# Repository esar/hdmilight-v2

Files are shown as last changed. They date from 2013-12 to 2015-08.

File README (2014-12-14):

For latest version, go to http://hacks.esar.org.uk/

How to use:

1) Manufacture the HDMI receiver board that can be found in 
   the 'board' directory (CADSoft Eagle format).
2) Open the 'fpga/hdmilight.xise' project in Xilinx ISE and
   generate a bit file.
3) Edit the files under the config directory to configure
   the LEDs.
4) Edit 'Makefile' in the top level directory and set
   the DATA2MEM path for the Xilinx data2mem tool location
   on your system.
5) Run 'make' in the top level directory, which will build
   'tools/makemem', then the firmware image, then the config
   files, before merging the firmware and config into the
   final bitfile.
   The final result should be hdmilight.bit in the top
   level directory.
6) Upload hdmilight.bit to a Papilio Pro FPGA board
7) Install the HDMI receiver board on to the Papilio board.
8) Connect LED strips to output pins
9) Open a serial terminal to the Papilio
10) Connect HDMI source to receiver board
11) It should now be working.

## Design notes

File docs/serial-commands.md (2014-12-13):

Serial Console Commands
=======================

Get Area
--------

    GA index

* index (0-255): The index or range of indices of the area definition(s) that should be retrieved 

Set Area
--------

    SA index xmin xmax ymin ymax divshift

* index (0-255): The index or range of indices of the area definition(s) that should be set
* xmin (0-63): The left most column of the area's rectangle
* xmax (0-63): The right most column of the area's rectangle
* ymin (0-63): The upper row of the area's rectangle
* ymax (0-63): The lower row of the area's rectangle
* divshift (0-): The number of places to right-shift the accumulated R, G and B value for the area, or in other words the divisor used to calculate the average
 * 1 = divide by 2
 * 2 = divide by 4
 * 3 = divide by 8
 * etc.

Reset Area
----------

    RA

Get Colour Correction Matrix
----------------------------

    GC matrix row 

* matrix (0-15): The index or range of indices of the matrix(s) whose row(s) should be retrieved
* row (0-3): The index or range of indices of the row(s) that should be retrieved:
  * Row 0: defines how red input influences the output R, G and B
  * Row 1: defines how green input influences the output R, G and B
  * Row 2: defines how blue input influences the output R, G and B
  * Row 3: defines the constant value that should be applied to the output R, G and B

Set Colour Correction Matrix
----------------------------

    SC matrix row r g b

* matrix (0-15): The index or range of indices of the matrix(s) whose row(s) should be set
* row (0-3): The index or range of indices of the row(s) that should be set
* r (-255.999-255.999): The coefficient for R
* g (-255.999-255.999): The coefficient for G
* b (-255.999-255.999): The coefficient for B

Reset Colour Correction Matrix
------------------------------

    RC

The reset colour command resets all colour correction matrices to the identity matrix.

Get Delay
---------

    GD

Set Delay
---------

    SD frames usec smooth_ratio

* frames (0-7): The number of whole frames that the output should be delayed by
* usec (0-65535): The number of micro-seconds that the output should be delayed by
* smooth_ratio (0.000-1.000): A number that specifies how much of the new output colour comes from the previous output colour and how much comes from the current frame:
 * 0.000 = 100% from current frame
 * 1.000 = 100% from previous output

Reset Delay
-----------

    RD

The reset delay command disables all delay and temporal smoothing

Disable Format Switching
------------------------

    DF

The disable format switching command stops configurations from being loaded
from flash whenever the format of the incoming video changes.

Enable Format Switching
-----------------------

    EF

The enable format switching command enables loading of the configurations
specified in the format table when the input video format changes.

Get Gamma
---------

    GG table channel index

* table (0-7): The index or range of indices of the gamma correction table(s) whose values should be retrieved
* channel (0-2): The index or range of indices of the colour channel(s) whose values should be retrieved: 
 * 0 = red
 * 1 = green
 * 2 = blue
* index: The index or range of indices of the row(s) that should be retrieved (0-255)

Set Gamma
---------

    SG table channel index value

* table (0-7): The index or range of indices of the gamma correction table(s) whose values should be set
* channel (0-2): The index or range of indices of the colour channel(s) whose values should be set
* index (0-255): The index or range of indices of the row(s) that should be set

Reset Gamma
-----------

    RG

The reset gamma command resets all gamma tables to a linear ramp (gamma 1.0)

Get I2C
-------

    GI addr subaddr

* addr (0-255): The address of the component within the ADV7611 that should be queried:
 * IO: 0x98
 * CP: 0x44
 * HDMI: 0x68
 * Repeater: 0x64
 * EDID: 0x6C
 * InfoFrame: 0x7C
 * CEC: 0x80
 * DPLL: 0x4C
* subaddr (0-255): The address within the component that should be queried

Set I2C
-------

    SI addr subaddr value

* addr (0-255): The address of the component within the ADV7611 that should be queried:
 * IO: 0x98
 * CP: 0x44
 * HDMI: 0x68
 * Repeater: 0x64
 * EDID: 0x6C
 * InfoFrame: 0x7C
 * CEC: 0x80
 * DPLL: 0x4C
* subaddr (0-255): The address within the component that should be queried
* value (0-255): The value that should be written to the register

Reset I2C
---------

    RI

The reset I2C command sets the registers as described in the table
in config_hdmi.h

Get Memory
----------

    GM index

* index (0-63): The index of the configuration that should be retrieved from flash

Get Output Map
--------------

    GO output light

* output (0-7): The index or indices of the output channels whose mapping should be retrieved
* light (0-511): The index or indices of the LED(s) whose mapping should be retrieved

Set Output Map
--------------

    SO output light area colour gamma enable

* output (0-7): The index or indices of the output channels whose mapping should be set
* light (0-511): The index or indices of the LED(s) whose mapping should be set
* area (0-255): The index of the area definition that the LED(s) should use
* colour (0-15): The index of the colour matrix that the LED(s) shoudl use
* gamma (0-7): The index of the gamma table that the LED(s) should use
* enable (0-1): 
 * 1 = enabled
 * 0 = disabled

Reset Output
------------

    RO

The reset output command sets the first 256 LEDs for all outputs to use the 256 area definitions in order, so LED 0 uses area 0, LED 1 uses area 1, and so on. All LEDs are set to use colour matrix 0 and gamma table 0. The remaining 256 LEDs on each output are disabled.

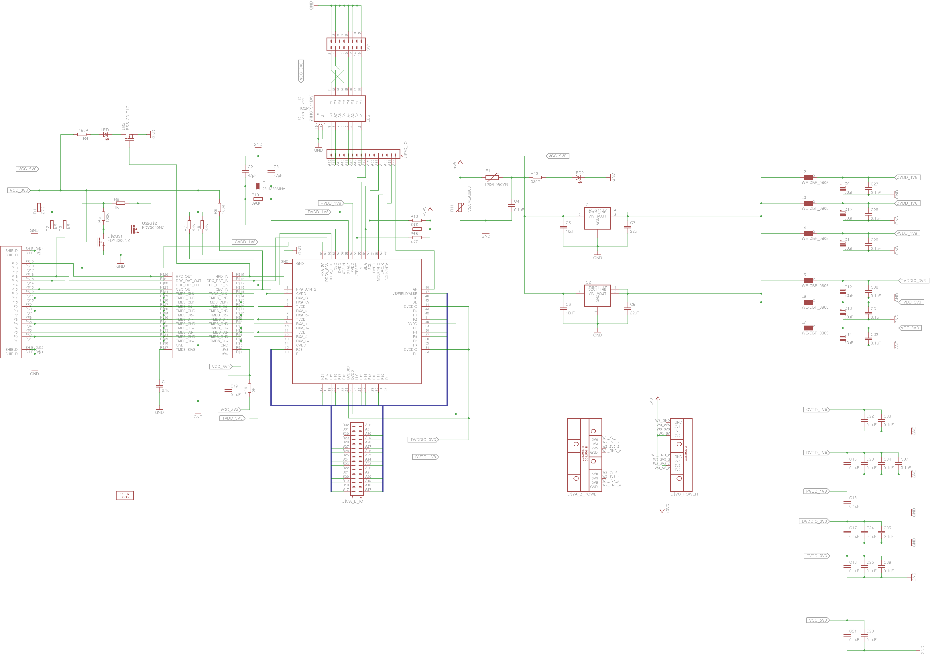
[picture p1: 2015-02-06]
board/hdmilight-schematic-v1.1.png

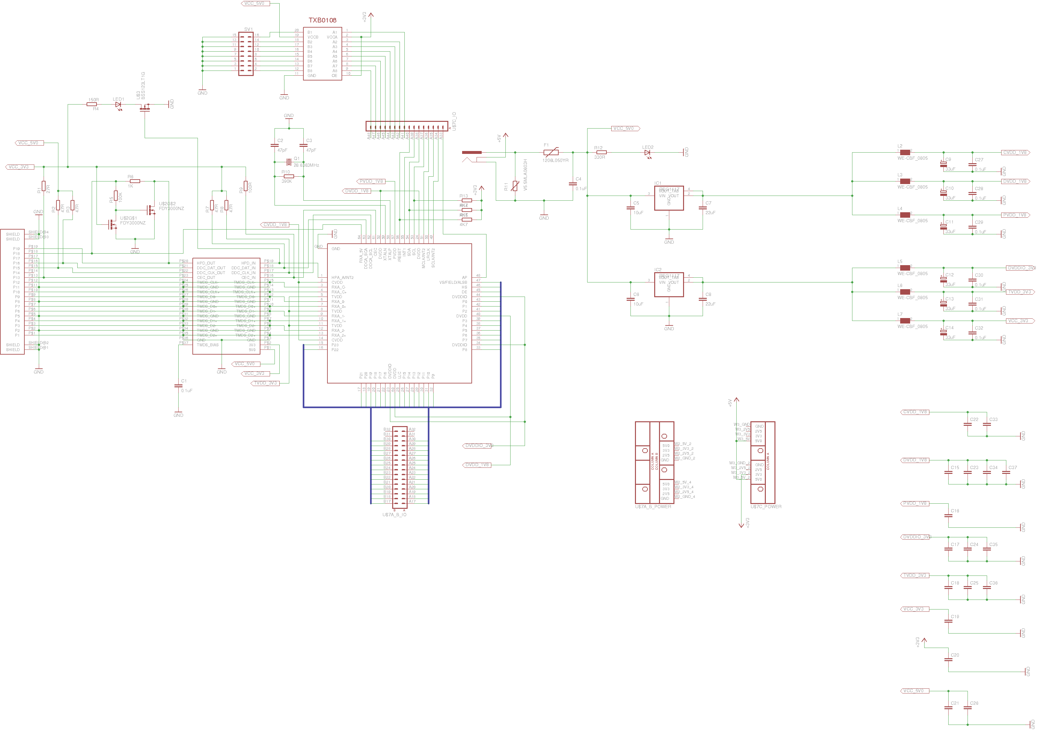
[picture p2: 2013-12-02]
board/hdmilight-schematic-v1.0.png

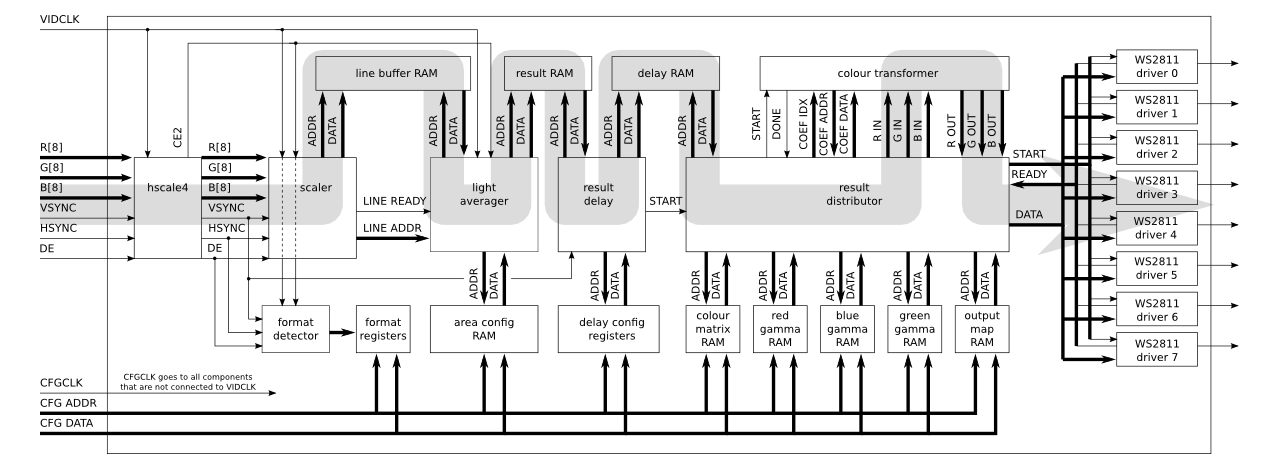
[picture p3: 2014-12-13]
docs/hdmilight-block-diagram.png

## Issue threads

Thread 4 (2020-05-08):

Need help with software

xfce, 2020-05-08:
Hi  all,
Does any one still do the project, I am  now designing a single board for this, means all in one board(FPGA+HDMI splitter) , but I think I can't do the software, could someone work together with me^-^
I use ubuntu 18.04 and ise 14.7, when install the license, got bellow, could someone help me

bi4wms@bi4wms-OptiPlex-390:/opt/Xilinx/14.7/ISE_DS$ xlcm-manage
Traceback (most recent call last):
  File "/usr/lib/command-not-found", line 28, in <module>
    from CommandNotFound import CommandNotFound
  File "/usr/lib/python3/dist-packages/CommandNotFound/CommandNotFound.py", line 19, in <module>
    from CommandNotFound.db.db import SqliteDatabase
  File "/usr/lib/python3/dist-packages/CommandNotFound/db/db.py", line 5, in <module>
    import apt_pkg
ImportError: /opt/Xilinx/14.7/ISE_DS/ISE/lib/lin64/libstdc++.so.6: version `CXXABI_1.3.8' not found (required by /usr/lib/python3/dist-packages/apt_pkg.cpython-36m-x86_64-linux-gnu.so)
Error in sys.excepthook:
Traceback (most recent call last):
  File "/usr/lib/python3/dist-packages/apport_python_hook.py", line 63, in apport_excepthook
    from apport.fileutils import likely_packaged, get_recent_crashes
  File "/usr/lib/python3/dist-packages/apport/__init__.py", line 5, in <module>
    from apport.report import Report
  File "/usr/lib/python3/dist-packages/apport/report.py", line 30, in <module>
    import apport.fileutils
  File "/usr/lib/python3/dist-packages/apport/fileutils.py", line 23, in <module>
    from apport.packaging_impl import impl as packaging
  File "/usr/lib/python3/dist-packages/apport/packaging_impl.py", line 24, in <module>
    import apt
  File "/usr/lib/python3/dist-packages/apt/__init__.py", line 23, in <module>
    import apt_pkg
ImportError: /opt/Xilinx/14.7/ISE_DS/ISE/lib/lin64/libstdc++.so.6: version `CXXABI_1.3.8' not found (required by /usr/lib/python3/dist-packages/apt_pkg.cpython-36m-x86_64-linux-gnu.so)

Original exception was:
Traceback (most recent call last):
  File "/usr/lib/command-not-found", line 28, in <module>
    from CommandNotFound import CommandNotFound
  File "/usr/lib/python3/dist-packages/CommandNotFound/CommandNotFound.py", line 19, in <module>
    from CommandNotFound.db.db import SqliteDatabase
  File "/usr/lib/python3/dist-packages/CommandNotFound/db/db.py", line 5, in <module>
    import apt_pkg
ImportError: /opt/Xilinx/14.7/ISE_DS/ISE/lib/lin64/libstdc++.so.6: version `CXXABI_1.3.8' not found (required by /usr/lib/python3/dist-packages/apt_pkg.cpython-36m-x86_64-linux-gnu.so)

esar, 2020-05-08:
Hi, it looks like the real problem is that it can't find the xlcm-manage program. The rest of the output is from the tool that is supposed to give you some suggestions on what to do, but it seems it's broken. You can see someone with a similar issue here:
https://unix.stackexchange.com/questions/9580/why-is-this-python-error-message-generated-whenever-i-type-a-nonsense-command

You might just need to specify the full path to the command. Does it find it if you run:
locate xlcm-manage

I don't have that program on my machines, but I'm still running ISE 14.4 so it might be something new.

BTW, what chipset are you using for the splitter?

xfce, 2020-05-09:
@esar Thanks, I will try .
For the splitter, I just find EP9132 , IT6661FN, still not deep in. and would you please give some advice?

esar, 2020-05-09:
I'm not sure I can give much advice. I've had a small amount of experience with the EP9132 and 9142, but only just enough to be able to stop them encrypting the output. You can read about my experiences with that here:
https://hacks.esar.org.uk/hdmi-splitter-hack/

The one thing that I did learn when doing that was that getting video output is pretty easy, the harder part is handling the feature support and crypto negotiation that the companion microcontroller handles. If you aren't interested in having the output encrypted then you might just need to relay the EDID info from the output port to the input port.

I've no idea if this will actually work, but I wonder if you could connect the DDC pins of the input port to the ADV7611 instead of the EP9132. Then detect when something is plugged into the output port, query its EDID info and write that to the EDID memory in the ADV7611 and then cycle the hotplug to made the source device re-read the EDID from the ADV7611. If that works then you may be able to avoid the companion EPF011A microcontroller and its firmware.

xfce, 2020-05-10:
@esar OK thanks , I will fellow your V3-HDMILIGHT, so close this issue.

Closed 2020-05-10.

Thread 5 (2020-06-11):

Write bit file to SPI FLASH error

xfce, 2020-06-11:
Hi @esar ,
 My single board have done, and write the hdmilight.bit to FPGA use Papilio Loader 2.8 is OK, also test the serial cmd, everything work, but can't write file to SPI FLASH, seems same error as my V3 board. can you help me use the openocd to write bit file to SPI FLASH, as V3 board I can try many times use openocd then write the bit file to SPI FLASH, THANKS
And if you can give me another type SPI FLASH for the FPGA, maybe I can have a try, THANKS

Bellow is the Papilio Loader's log
Using devlist.txt
JTAG chainpos: 0 Device IDCODE = 0x24001093	Desc: XC6SLX9
Using devlist.txt
JTAG chainpos: 0 Device IDCODE = 0x24001093	Desc: XC6SLX9
Trying reconfigure

Uploading "/opt/GadgetFactory/papilio-loader/programmer/bscan_spi_xc6slx9.bit". DNA is 0x59faae82210299fe
Done.
Programming time 552.0 ms

Programming External Flash Memory with "/home/bi4wms/Downloads/hdmilight-v2-master/hdmilight.bit".
Uknown Flash Manufacturer (0x01)
Error: SPI Status Register [0xFF] mismatch (Wrong device or device not ready)..
Error occured.
USB transactions: Write 178 read 9 retries 9
Using devlist.txt
JTAG chainpos: 0 Device IDCODE = 0x24001093	Desc: XC6SLX9

ISC_Done       = 0
ISC_Enabled    = 0
House Cleaning = 1
DONE           = 0

esar, 2020-06-11:
@xfce When you say that the serial commands work, do you mean the HDMI Light commands, like ? showing the help? If that works then the write to the FPGA flash must have worked as in this version the CPU is implemented in the FPGA and the firmware is stored in the FPGA flash

There will be a problem with using openocd with the v2 project at the moment. There is currently no tool that can append config.bin to the binary .bin file that openocd can write. Currently the tools only know how to append it to the .bit version of the file. Making it work would require doing the folowing:
1) Copy hdmilight-v3-openocd.cfg from the v3 project and remove this line: source [find target/stm32f3x.cfg]
2) In Xilinx ISE change the project settings to also generate a .bin file as well as the .bit
3) Update the DATA2MEM command to merge the firmware into the .bin file instead of the .bit file... modify this command in the Makefile:
$(DATA2MEM) -bm fpga/progmem_bd.bmm -bt fpga/HdmilightTop.bit -bd firmware/image.mem -o b hdmilight-preconfig.bit
4) Add support to tools/bitmerge.py to make it work with the .bin format file
5) Use the openocd command from the v3 project to write the merged .bin file:
openocd -f hdmilight-v3-openocd.cfg -c "init; targets xc6s.proxy; jtagspi_init 0 bscan_spi_xc6slx9.bit; jtagspi_program hdmilight.bin 0; xc6s_program xc6s.tap; shutdown"

I don't know if this is actually possible, and there are probably mistakes in these instructions, but that is roughly what needs to be done

xfce, 2020-06-12:
Hi @esar ,
   I have  used  the openocd -f hdmilight-v3-openocd.cfg ...  command ,and can finish to write the SPI flash.
But I can't get the right hdmilight.bin file, so for your step3 and step4 above, could you please help me, give the complete command, thanks a lot

esar, 2020-06-13:
@xfce If the serial commands are working ok then the PapilioLoader must have successfully written the bit file to the FPGA flash. Is the problem just that you can't write it a second time?
If that is the case then you could try holding the FPGA reset, then starting the loader, and then quickly releasing the reset. This might help if the running design is interfering with writing.

Regarding using openocd, you will either need to update the tools to generate a .bin file instead of a .bit file, or leave the tools working with the .bit file as they do now and then find a way to convert the .bit file to a .bin file.
The .bin file is just the raw data that needs to be written to the flash. The .bit file is sort of the same but it has some extra headers on the beginning that need removing.
I don't know the commands that are needed to do this, and I don't have time to work out how to do it at the moment.

xfce, 2020-06-14:
Hi @esar
    I have found a tool /opt/Xilinx/14.4/ISE_DS/ISE/bin/lin64/promgen,  and just use this to convert hdmilight.bit to hdmilight.bin by command
root@bi4wms-ThinkPad-X230:/home/bi4wms/Downloads/hdmilight-v2-master# /opt/Xilinx/14.4/ISE_DS/ISE/bin/lin64/promgen -spi -w -p bin -u 0 hdmilight.bit
Release 14.4 - Promgen P.49d (lin64)
Copyright (c) 1995-2012 Xilinx, Inc.  All rights reserved.
0x7e806 (518150) bytes loaded up from 0x0
Using generated prom size of 512K
Writing file "hdmilight.bin".
Writing file "hdmilight.prm".
Writing file "hdmilight.cfi".
root@bi4wms-ThinkPad-X230:/home/bi4wms/Downloads/hdmilight-v2-master#

then i use the openocd download

root@bi4wms-ThinkPad-X230:/home/bi4wms/Downloads/hdmilight-v2-master# openocd -f hdmilight-v3-openocd.cfg -c "init; targets xc6s.proxy; jtagspi_init 0 bscan_spi_xc6slx9.bit; jtagspi_program hdmilight.bin 0; xc6s_program xc6s.tap; shutdown"
Open On-Chip Debugger 0.10.0+dev-01267-g4c364b45-dirty (2020-06-04-06:32)
Licensed under GNU GPL v2
For bug reports, read
	http://openocd.org/doc/doxygen/bugs.html
DEPRECATED! use 'adapter driver' not 'interface'
DEPRECATED! use 'adapter speed' not 'adapter_khz'
none separate

Info : clock speed 1000 kHz
Info : JTAG tap: xc6s.tap tap/device found: 0x24001093 (mfg: 0x049 (Xilinx), part: 0x4001, ver: 0x2)
Info : JTAG tap: xc6s.tap tap/device found: 0x24001093 (mfg: 0x049 (Xilinx), part: 0x4001, ver: 0x2)
Info : Found flash device 'cyp s25fl064l' (ID 0x00176001)
Info : Found flash device 'cyp s25fl064l' (ID 0x00176001)
Info : Found flash device 'cyp s25fl064l' (ID 0x00176001)
Info : Found flash device 'cyp s25fl064l' (ID 0x00176001)
Info : sector 0 took 444 ms
Info : sector 1 took 484 ms
Info : sector 2 took 481 ms
Info : sector 3 took 458 ms
Info : sector 4 took 461 ms
Info : sector 5 took 457 ms
Info : sector 6 took 445 ms
Info : sector 7 took 456 ms
Info : Found flash device 'cyp s25fl064l' (ID 0x00176001)
shutdown command invoked
root@bi4wms-ThinkPad-X230:/home/bi4wms/Downloads/hdmilight-v2-master#

seems OK, and most serial command response OK, but the LED strip can't work, just the first one lit up green.
the wrong serial command response is GF
> GF                                                                       
raw: 0 0 0 0 0 0                                                           
fmt: -1x-1 1.77 (0)
and for V3 got bellow
> GF                                                                       
raw: 1916 0 4 1080 0 0                                                     
fmt: 1916x1080 1.77 (0)

esar, 2020-06-14:
@xfce From that GF command it looks like the FPGA is not receiving a video signal from the ADV7611.

Do you have all of the pins between the ADV7611 and the FPGA connected to the same FPGA pins as on the original v2 design? Or did you change some to make routing easier?

If you run these two commands to read the version number from the ADV7611, do you get 0x20 and 0x51 as the result?:
GI 0x98 0xea
GI 0x98 0xeb

Can you run the "R" command? What output does it give?
It should output a long list of register addresses, each followed by either ACK or NACK
Does the GF output change after running R?

If there is still no change then can you check the LLC, VS, HS and DE signals from the ADV7611 with an oscilloscope and see if there is any activity?
LLC is the main video clock, depending on the mode it will be up to about 166MHz
VS and HS are the horizontal and vertical sync pulses, there should be one HS pulse per line of video, and one VS pulse per frame.
DE is data enable and marks which parts of each line contain valid pixel data. It should pulse at a similar rate to the HS signal.

xfce, 2020-06-14:
> GF                                                                         
raw: 0 0 0 0 0 0                                                             
fmt: -1x-1 1.77 (0)                                                          
                                                                             
> GI 0x98 0xea                                                               
Read: 32 (0x20)                                                              
                                                                             
> GI 0x98 0xeb                                                               
Read: 81 (0x51)                                                              
                                                                             
> R                                                                          
152 244 128 : NACK NACK                                                      
> GF                                                                         
raw: 0 0 0 0 0 0                                                             
fmt: -1x-1 1.77 (0)                                                          
>

xfce, 2020-06-14:
Hi @esar ,
   I found schematic is different from the hdmilight.ucf, changed ,seems something change
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
esar, 2020-06-14:
@xfce The GPIO pins are just spare pins that can be used for future expansion. They are mapped to PORTD in the AVR microcontroller.

When you connect a video source, does the GF command give different output? Or does it always give the same 636x480?
Does the LED by the HDMI port light when the video source is connected?
What resolution is the video source?

xfce, 2020-06-15:
@esar When HDMI source connect, GF still give the same output, always same 636*480.
And  also LED still off , only I type “R” then the first 20 LEDs turn blue, video source is 1920*1080, cause HDMIlightV3 all  OK.

esar, 2020-06-15:
@xfce You don't need to change anything else for the changed pins. That problem is now fixed as you now get 640x480 video from the ADV7611 instead of 0x0. That 640x480 video signal is being generated internally in the ADV7611. It is the blue screen that is displays when there is not a video source.

Because you only get the blue LEDs when you run the R command, the firmware must not be initialising automatically. There is a #define in main.c that should be enabled by default, but it looks like that isn't working. For now you will need to always run R, we can work out what that problem is after we get incoming video working.

The main problem now seems to be that the ADV7611 doesn't think there is a video source. Maybe there are some bad connections between the HDMI connector, the ESD chip, and the ADV7611.

Because the LED doesn't light that tells us that the ADV7611 is not asserting HPA. This signal is used to tell the video source that something is connected and that it can read the EDID to find the supported resolutions and then send video. The ADV7611 should assert this signal when the EDID RAM has been written (happens when you run R) and when it detects a cable plugged in.

The first thing that I would check is if there is 5V on pin 64 of the ADV7611. This 5V comes from the HDMI cable and tells the ADV7611 that a cable is connected. If this is present then next check HPA_A on pin 1 of the ADV7611 to see if it is high, then follow the signal through the ESD chip and the transistor pair

xfce, 2020-06-16:
Hi @esar ,
As fellow your clues, found the HPA_A signal was strange, and finaly I resolder a new ADV7611, then power up with no HDMI signal, type GF, give 640*480, plugin HDMI signal, type GF again,give 1920*1080, seems everything worked, Thanks a lot.

Closed 2020-06-16.

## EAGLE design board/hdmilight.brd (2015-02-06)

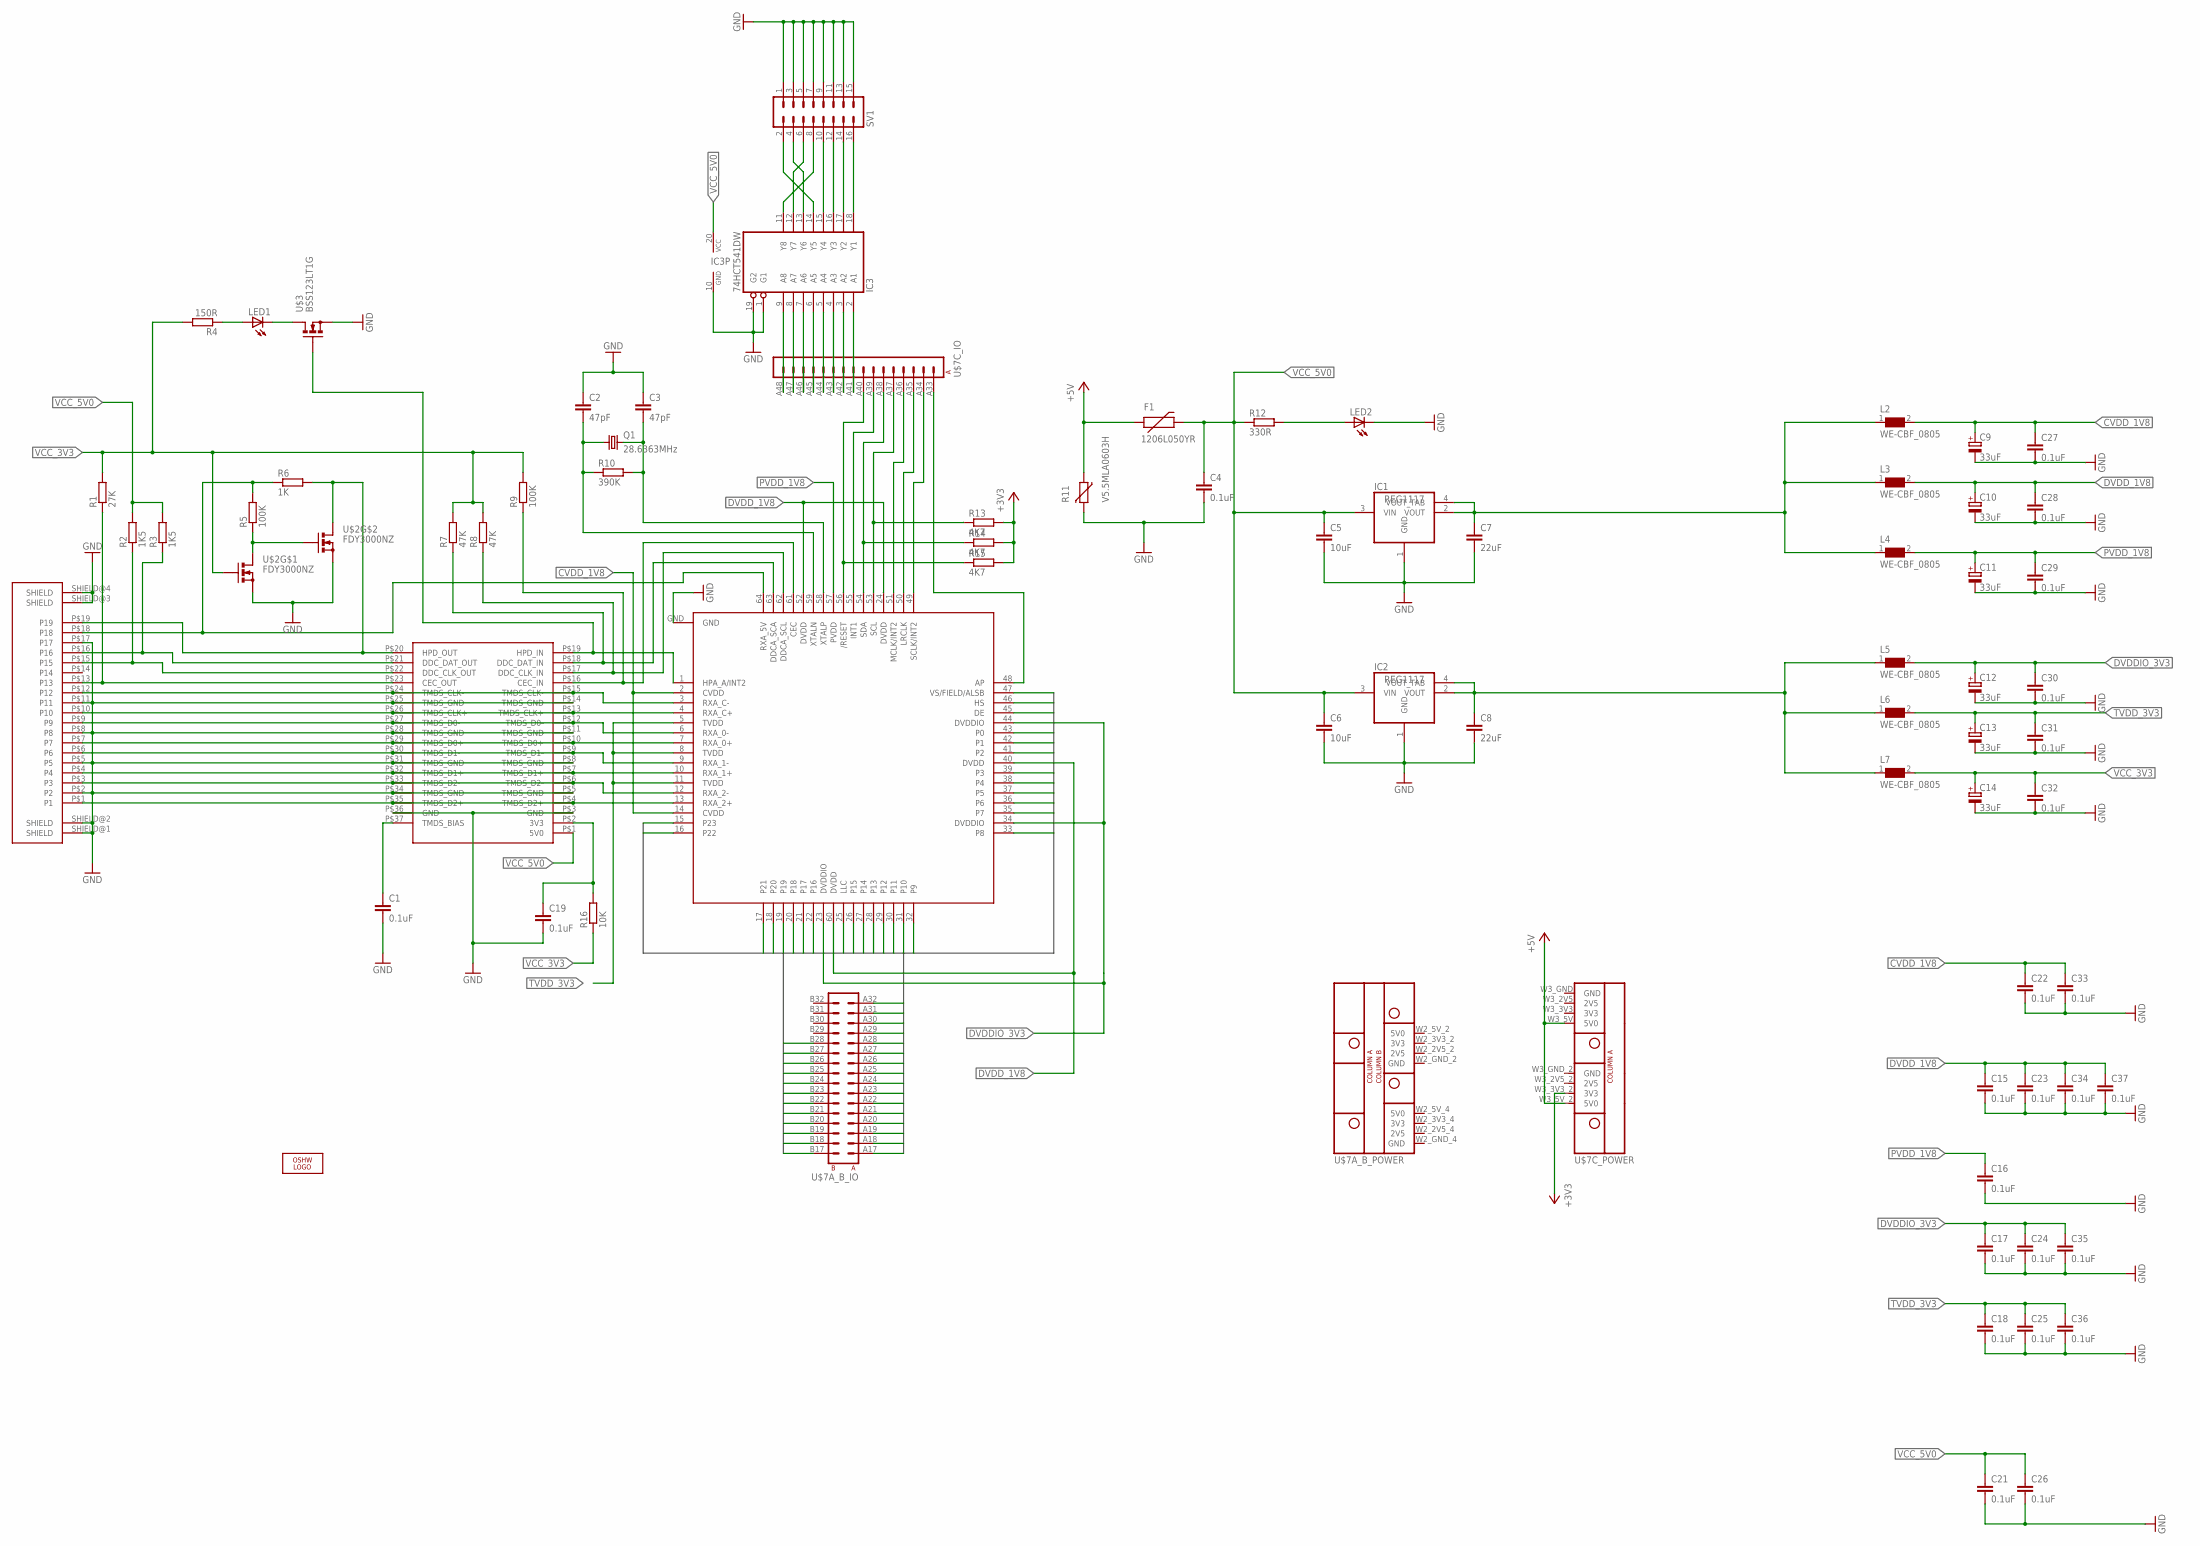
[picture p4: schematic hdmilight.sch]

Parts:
C1, C4, C16, C17, C19, C21, C22, C24, C26, C27, C28, C29, C30, C31, C32, C33: 0.1uF; C0603
C2, C3: 47pF; C0603
C5, C6: 10uF; C1210
C7, C8: 22uF; C1206
C9, C10, C11, C12, C13, C14: 33uF; SMC_B
C15, C18, C23, C25, C34, C35, C36, C37: 0.1uF; C0402
F1: 1206L050YR; PTC-1206
IC1, IC2: REG1117; SOT223
IC3: 74HCT541DW; SO20W
L2, L3, L4, L5, L6, L7: WE-CBF_0805; 0805
LED1, LED2: LEDCHIP-LED0805; CHIP-LED0805
LOGO1: OSHW_LOGO_FILLX0200-NT; OSHW_FILLX200_NOTEXT
Q1: 28.6363MHz; SM49
R1: 27K; R0603
R2, R3: 1K5; R0603
R4: 150R; R0603
R5, R9: 100K; R0603
R6: 1K; R0603
R7, R8: 47K; R0603
R10: 390K; R0603
R11: V5.5MLA0603H; CT/CN0603
R12: 330R; R0603
R13, R14, R15: 4K7; R0603
R16: 10K; R0603
SV1: MA08-2
U$1: FCI_HDMI_SOCKET_10029449-001RCF
U$2: FDY3000NZ; SC89-6
U$3: BSS123LT1G; SOT23
U$4: TPD12S520; TSSOP38
U$6: ADV7611; TQFP64-10X10
U$7: MEGAWING_FULL_P1MEGAWING_P1; MEGAWING_FULL_NOHOLES_P1

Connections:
+3V3: R13.2, R14.2, R15.2, U$7.W3_3V3_2 (3V3)
+5V: F1.1, R11.1, U$7.W3_5V (5V0), U$7.W3_5V_2 (5V0)
CVDD_1V8: C9.+, C22.1, C27.1, C33.1, L2.2, U$6.2 (CVDD), U$6.14 (CVDD)
DE: U$6.45 (DE), U$7.B18 (B2)
DVDDIO_3V3: C12.+, C17.1, C24.1, C30.1, C35.1, L5.2, U$6.23 (DVDDIO), U$6.34 (DVDDIO), U$6.44 (DVDDIO)
DVDD_1V8: C10.+, C15.1, C23.1, C28.1, C34.1, C37.1, L3.2, U$6.24 (DVDD), U$6.40 (DVDD), U$6.52 (DVDD), U$6.60 (DVDD)
GND: C1.2, C2.1, C3.1, C4.2, C5.2, C6.2, C7.2, C8.2, C9.-, C10.-, C11.-, C12.-, C13.-, C14.-, C15.2, C16.2, C17.2, C18.2, C19.2, C21.2, C22.2, C23.2, C24.2, C25.2, C26.2, C27.2, C28.2, C29.2, C30.2, C31.2, C32.2, C33.2, C34.2, C35.2, C36.2, C37.2, IC1.1 (GND), IC2.1 (GND), IC3.1 (G1), IC3.10 (GND), IC3.19 (G2), LED2.C, R11.2, SV1.1, SV1.3, SV1.5, SV1.7, SV1.9, SV1.11, SV1.13, SV1.15, U$1.P$2 (P2), U$1.P$5 (P5), U$1.P$8 (P8), U$1.P$11 (P11), U$1.P$17 (P17), U$1.SHIELD@1 (SHIELD), U$1.SHIELD@2 (SHIELD), U$1.SHIELD@3 (SHIELD), U$1.SHIELD@4 (SHIELD), U$2.P$1 (S), U$2.P$4 (S), U$3.2 (S), U$4.P$3 (GND), U$4.P$5 (TMDS_GND), U$4.P$8 (TMDS_GND), U$4.P$11 (TMDS_GND), U$4.P$14 (TMDS_GND), U$4.P$25 (TMDS_GND), U$4.P$28 (TMDS_GND), U$4.P$31 (TMDS_GND), U$4.P$34 (TMDS_GND), U$4.P$36 (GND), U$6.GND, U$7.W2_GND_2 (GND), U$7.W2_GND_4 (GND), U$7.W3_GND (GND), U$7.W3_GND_2 (GND)
HS: U$6.46 (HS), U$7.A17 (A1)
LLC: U$6.25 (LLC), U$7.A30 (A14)
unnamed: U$1.P$1 (P1), U$4.P$4 (TMDS_D2+), U$4.P$35 (TMDS_D2+), U$6.13 (RXA_2+)
unnamed: U$1.P$3 (P3), U$4.P$6 (TMDS_D2-), U$4.P$33 (TMDS_D2-), U$6.12 (RXA_2-)
unnamed: U$1.P$4 (P4), U$4.P$7 (TMDS_D1+), U$4.P$32 (TMDS_D1+), U$6.10 (RXA_1+)
unnamed: U$1.P$6 (P6), U$4.P$9 (TMDS_D1-), U$4.P$30 (TMDS_D1-), U$6.9 (RXA_1-)
unnamed: U$1.P$7 (P7), U$4.P$10 (TMDS_D0+), U$4.P$29 (TMDS_D0+), U$6.7 (RXA_0+)
unnamed: U$1.P$9 (P9), U$4.P$12 (TMDS_D0-), U$4.P$27 (TMDS_D0-), U$6.6 (RXA_0-)
unnamed: U$1.P$10 (P10), U$4.P$13 (TMDS_CLK+), U$4.P$26 (TMDS_CLK+), U$6.4 (RXA_C+)
unnamed: U$1.P$12 (P12), U$4.P$15 (TMDS_CLK-), U$4.P$24 (TMDS_CLK-), U$6.3 (RXA_C-)
unnamed: IC3.9 (A8), U$7.A48 (A16)
unnamed: IC3.8 (A7), U$7.A47 (A15)
unnamed: IC3.7 (A6), U$7.A46 (A14)
unnamed: IC3.6 (A5), U$7.A45 (A13)
unnamed: R1.1, U$1.P$13 (P13), U$4.P$23 (CEC_OUT)
unnamed: R2.1, U$1.P$15 (P15), U$4.P$22 (DDC_CLK_OUT)
unnamed: R3.1, U$1.P$16 (P16), U$4.P$21 (DDC_DAT_OUT)
unnamed: R6.2, U$1.P$19 (P19), U$2.P$3 (D), U$4.P$20 (HPD_OUT)
unnamed: IC3.5 (A4), U$7.A44 (A12)
unnamed: IC3.4 (A3), U$7.A43 (A11)
unnamed: LED2.A, R12.2
unnamed: R8.1, U$4.P$17 (DDC_CLK_IN), U$6.62 (DDCA_SCL)
unnamed: C8.1, IC2.2 (VOUT), IC2.4 (VOUT_TAB), L5.1, L6.1, L7.1
unnamed: C7.1, IC1.2 (VOUT), IC1.4 (VOUT_TAB), L2.1, L3.1, L4.1
unnamed: R7.1, U$4.P$18 (DDC_DAT_IN), U$6.63 (DDCA_SCA)
unnamed: R9.1, U$4.P$16 (CEC_IN), U$6.61 (CEC)
unnamed: C2.2, Q1.1, R10.1, U$6.59 (XTALN)
unnamed: C3.2, Q1.2, R10.2, U$6.58 (XTALP)
unnamed: U$6.49 (SCLK/INT2), U$7.A34 (A2)
unnamed: U$6.50 (LRCLK), U$7.A35 (A3)
unnamed: U$6.48 (AP), U$7.A33 (A1)
unnamed: R13.1, U$6.53 (SCL), U$7.A37 (A5)
unnamed: R14.1, U$6.54 (SDA), U$7.A38 (A6)
unnamed: U$6.55 (INT1), U$7.A39 (A7)
unnamed: R15.1, U$6.56 (/RESET), U$7.A40 (A8)
unnamed: C1.1, U$4.P$37 (TMDS_BIAS)
unnamed: IC3.3 (A2), U$7.A42 (A10)
unnamed: IC3.2 (A1), U$7.A41 (A9)
unnamed: IC3.14 (Y5), SV1.2
unnamed: IC3.11 (Y8), SV1.8
unnamed: IC3.12 (Y7), SV1.6
unnamed: IC3.13 (Y6), SV1.4
unnamed: IC3.15 (Y4), SV1.10
unnamed: IC3.16 (Y3), SV1.12
unnamed: U$6.51 (MCLK/INT2), U$7.A36 (A4)
unnamed: IC3.17 (Y2), SV1.14
unnamed: IC3.18 (Y1), SV1.16
unnamed: C19.1, R16.2, U$4.P$2 (3V3)
unnamed: R5.1, U$2.P$5 (G), U$2.P$6 (D)
unnamed: R5.2, R6.1, U$1.P$18 (P18), U$6.64 (RXA_5V)
unnamed: LED1.A, R4.1
unnamed: LED1.C, U$3.3 (D)
unnamed: U$3.1 (G), U$4.P$19 (HPD_IN), U$6.1 (HPA_A/INT2)
P0: U$6.43 (P0), U$7.A18 (A2)
P1: U$6.42 (P1), U$7.B19 (B3)
P2: U$6.41 (P2), U$7.A19 (A3)
P3: U$6.39 (P3), U$7.B20 (B4)
P4: U$6.38 (P4), U$7.A20 (A4)
P5: U$6.37 (P5), U$7.B21 (B5)
P6: U$6.36 (P6), U$7.A21 (A5)
P7: U$6.35 (P7), U$7.B22 (B6)
P8: U$6.33 (P8), U$7.A22 (A6)
P9: U$6.32 (P9), U$7.B23 (B7)
P10: U$6.31 (P10), U$7.A23 (A7)
P11: U$6.30 (P11), U$7.B24 (B8)
P12: U$6.29 (P12), U$7.A24 (A8)
P13: U$6.28 (P13), U$7.B25 (B9)
P14: U$6.27 (P14), U$7.A25 (A9)
P15: U$6.26 (P15), U$7.B26 (B10)
P16: U$6.22 (P16), U$7.A26 (A10)
P17: U$6.21 (P17), U$7.B27 (B11)
P18: U$6.20 (P18), U$7.A27 (A11)
P19: U$6.19, U$7.B28 (B12)
P20: U$6.18 (P20), U$7.A28 (A12)
P21: U$6.17 (P21), U$7.A29 (A13)
P22: U$6.16 (P22), U$7.A31 (A15)
P23: U$6.15 (P23), U$7.A32 (A16)
PVDD_1V8: C11.+, C16.1, C29.1, L4.2, U$6.57 (PVDD)
TVDD_3V3: C13.+, C18.1, C25.1, C31.1, C36.1, L6.2, U$6.5 (TVDD), U$6.8 (TVDD), U$6.11 (TVDD)
VCC_3V3: C14.+, C32.1, L7.2, R1.2, R4.2, R7.2, R8.2, R9.2, R16.1, U$2.P$2 (G)
VCC_5V0: C4.1, C5.1, C6.1, C21.1, C26.1, F1.2, IC1.3 (VIN), IC2.3 (VIN), IC3.20 (VCC), R2.2, R3.2, R12.1, U$4.P$1 (5V0)
VS: U$6.47 (VS/FIELD/ALSB), U$7.B17 (B1)

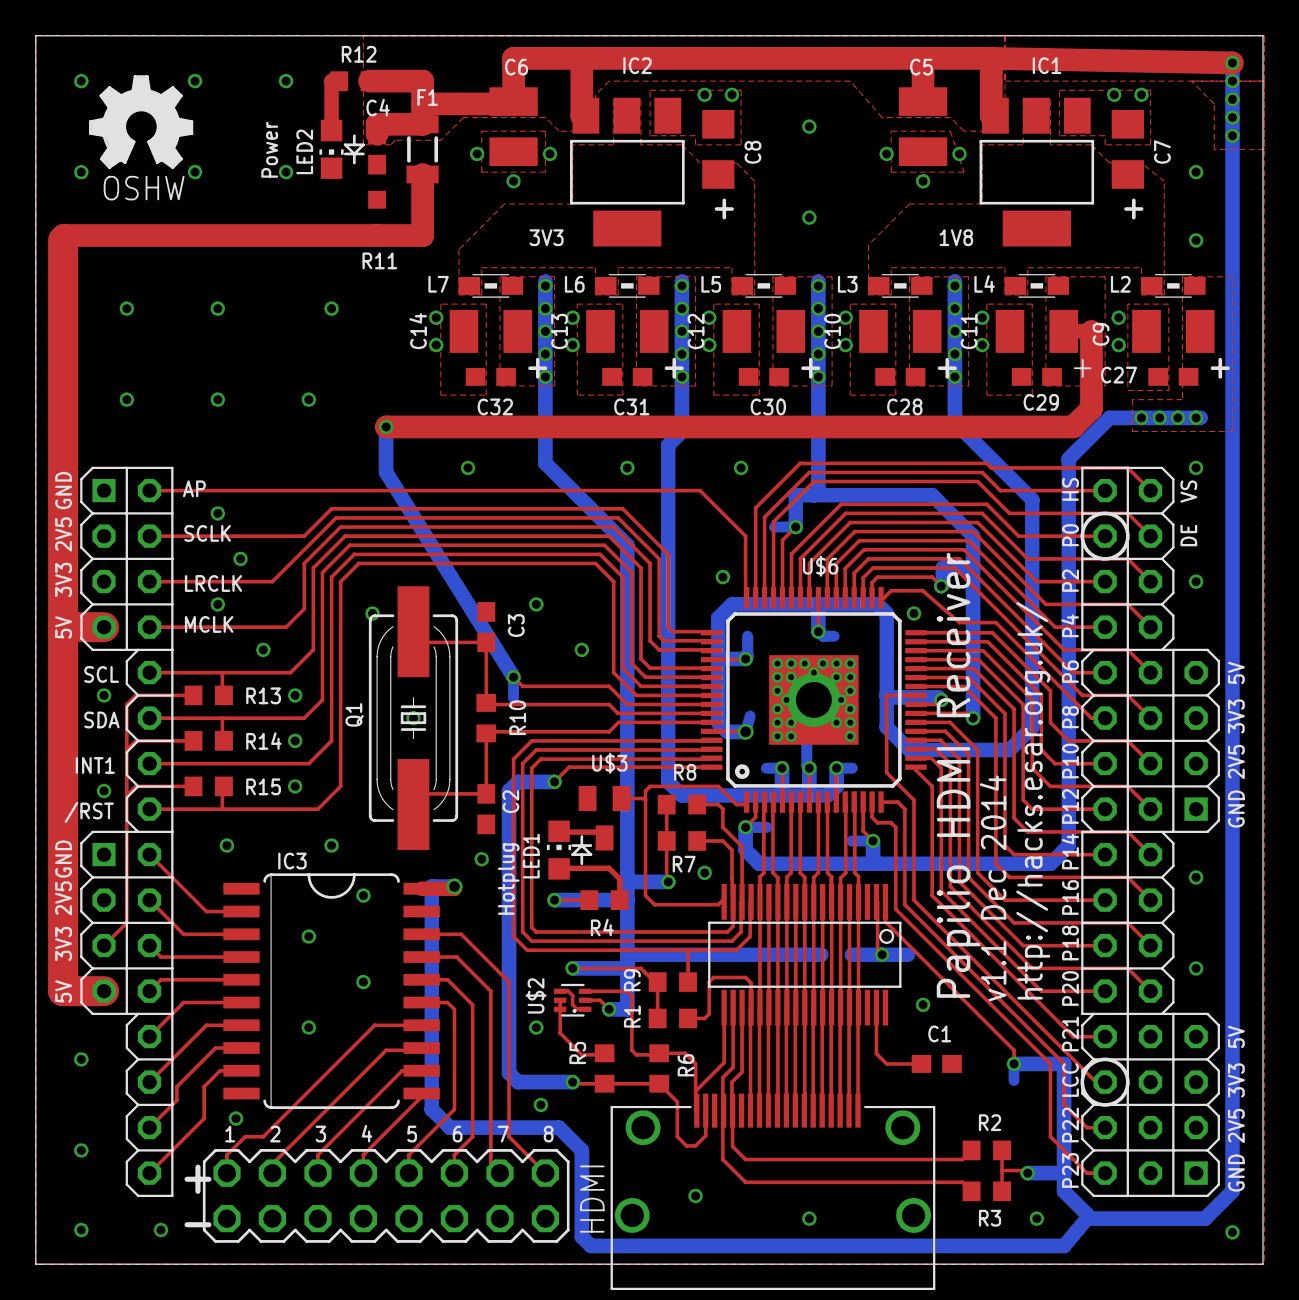
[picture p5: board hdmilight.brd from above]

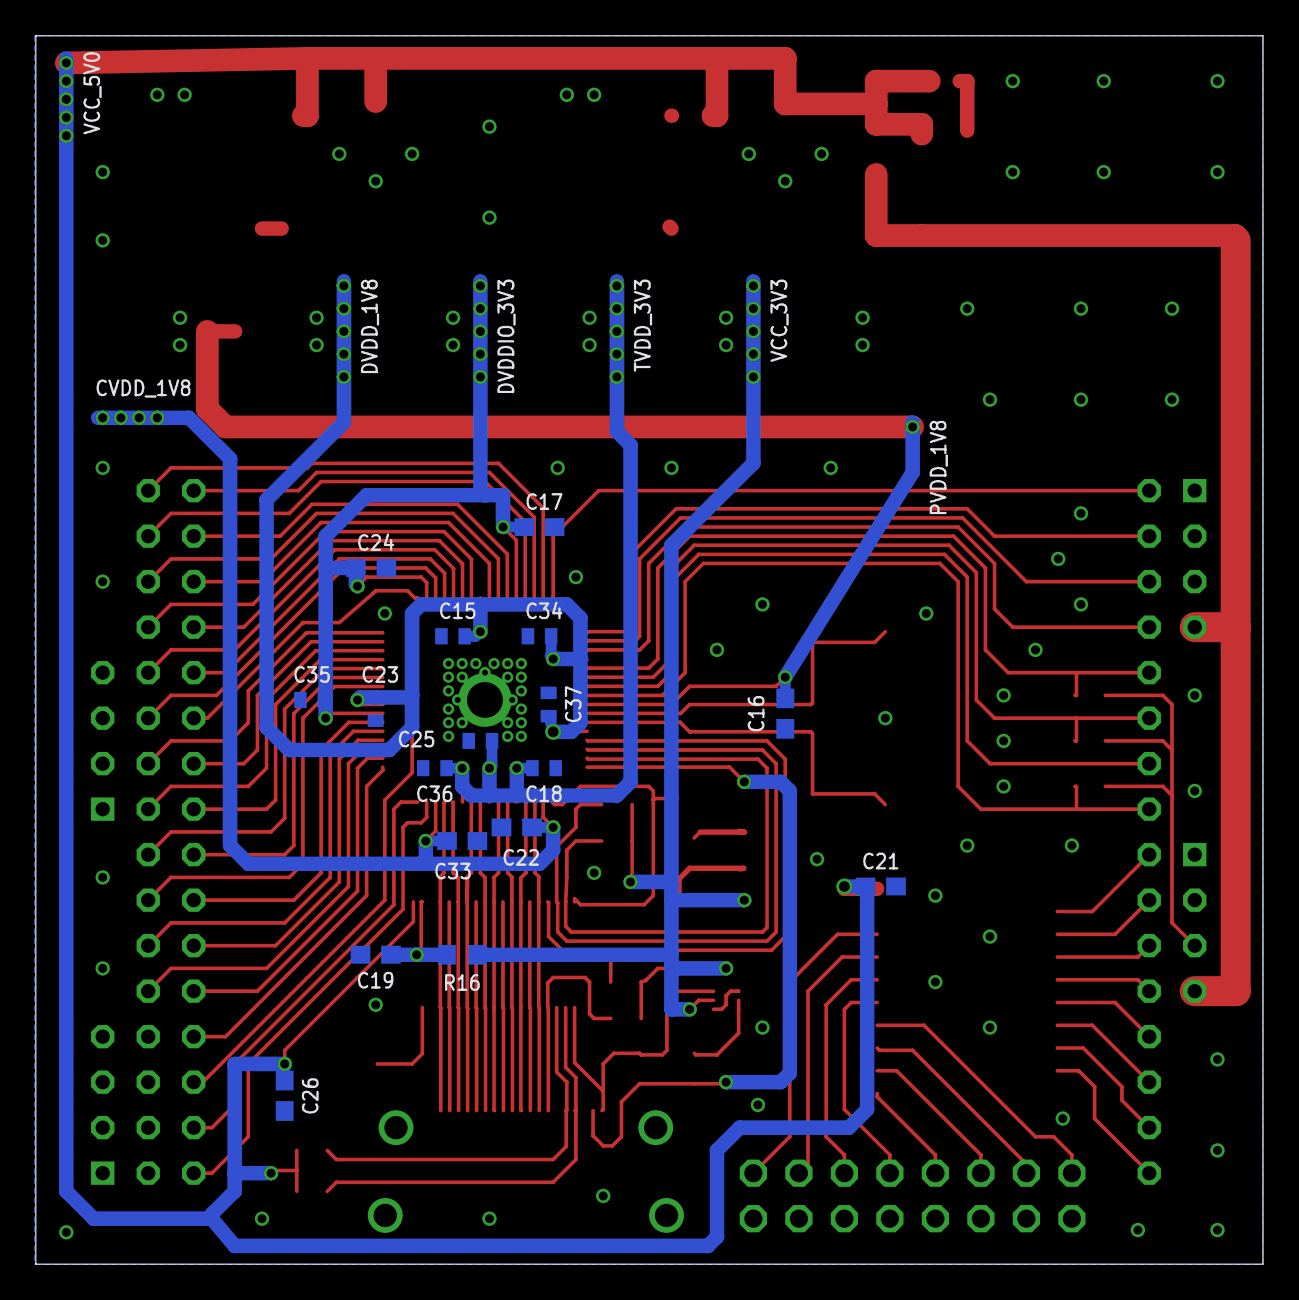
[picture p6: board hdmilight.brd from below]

Board: 2 copper layers, 68.5 x 68.6 mm, 73 parts (17 on the bottom side), 89 nets.

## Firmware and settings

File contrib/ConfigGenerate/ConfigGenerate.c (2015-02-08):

/*

   Copyright (C) 2015 Jetty

   This file is part of HDMI-Light

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
*/

#include <stdio.h>
#include <math.h>

/*
	Generates a basic Hdmilight configuration that has strips of LEDs wired in the following order on 1 output.  The intention
	is to provide a simple configuration to begin with, that can be adapted later:

	Wire in this order:
		Power/Data -> Top (Going Left to Right)
		Right (Going Top to Bottom)
		Bottom (Going Right to Left)
		Left (Going Bottom to Top)

	The following files are generated:
		area.conf
		output_N.conf

	It's assumed that top/bottom led strips  have the same number of leds and left/right leds strips have the same number of leds

	The total number of LEDS must be <=512
*/

// The number of the output we want to generate the files for
#define	OUTPUT_NUM 0 	// Valid values are 0-7 (and integer) and map to outputs 1-8 on the Hdmilight v2 board

// Set to the width / height of the picture (you can obtain this via the GF (get format) command in the serial interface
#define PIXELS_WIDTH  1916	// Must be integer
#define PIXELS_HEIGHT 1080	// Must be integer

// LEDS_X * 2 + LEDS_Y * 2  must be <= 512, if it's not, then your configuration will span more than 1 output, and this
// tool is not for you
#define LEDS_X	73	// Number of X leds (number of LEDs in each of the Top and Bottom Rows), must be integer
#define LEDS_Y	41	// Number of Y leds (number of LEDs in each of the Left and Right Columns, must be integer

// Fine tuning the bounds of the screen
// The screen is divided into a grid of cells of VIDEO_SCALING x VIDEO_SCALING in pixels by the FPGA
// Because the picture may not fit completely in the cell grid, we provide the opportunity here to adjust the 
// the bounds of the cell grid.  Negative values will shift the cell grid boudns to the left, and positive values to the right.
// The starting offsets should be >= 0, and values -2 to 2 would be normal.
// Start off with the values at 0, if you have a left most led in X that is not displaying a color, the video is out of bounds,
// increase by 1 and try again.  If the right most led in X is not correct, then you will want to decrease the end X offset by 1
//
// The cell grid could like this before adjustment, where P is the picture.  Both P and X are units of VIDEO_SCALING * VIDEO_SCALING
// in size:
//  X X X X X X X X X X X X X
//  X P P P P P P P P P P P X
//  X P P P P P P P P P P P X
//  X P P P P P P P P P P P X
//  X P P P P P P P P P P P X
//  X P P P P P P P P P P P X
//
//  To fix this and achieve:
//  P P P P P P P P P P P
//  P P P P P P P P P P P
//  P P P P P P P P P P P
//  P P P P P P P P P P P
//  P P P P P P P P P P P
//
//	CELLGRID_BOUNDS_START_X_OFFSET 	1
//	CELLGRID_BOUNDS_END_X_OFFSET	-1
//	CELLGRID_BOUNDS_START_Y_OFFSET 	1
//	CELLGRID_BOUNDS_END_Y_OFFSET	0
//
#define CELLGRID_BOUNDS_START_X_OFFSET 	0	// Adjustment to the first cell we want to use for the LEDS, must be >=0, typically <=2 and integer
#define CELLGRID_BOUNDS_END_X_OFFSET	0	// Adjustment to the last cell we want to use for the LEDS, typically -2 to +2 and integer
#define CELLGRID_BOUNDS_START_Y_OFFSET 	0	// Adjustment to the first cell we want to use for the LEDS, must be >=0, typically <=2 and integer
#define CELLGRID_BOUNDS_END_Y_OFFSET	0	// Adjustment to the last cell we want to use for the LEDS, typically -2 to +2 and integer

// The cell grid is further divided into areas which surround the outside the screen
// The following are in units of cells and are integers.  The minimum size is 1 cell.
// 
// For the top/bottom rows, AREA_WIDTH is in X and AREA_DEPTH is in Y, i.e AREA_WIDTH=2, AREA_DEPTH = 8, defines an area that is sized
// X: 2 * VIDEO_SCALING and Y:8 * VIDEO_SCALING
//
// For the left/right columns, AREA_WIDTH is in Y and AREA_DEPTH is in X, i.e AREA_WIDTH=2, AREA_DEPTH = 8, defines an area that is sized
// Y: 2 * VIDEO_SCALING and X:8 * VIDEO_SCALING
//
// Normally, where you have more LEDs than cells, you would have an AREA_WIDTH = 1
// If you have significantly fewer LEDS than cells, then AREA_WIWDTH = 2, or maybe 3
//
// AREA_DEPTH controls have far the sample area stretches from the edges of the screen.  Larger numbers take a large
// sample area to calculate the resulting color of the LED
//
// AREA_WIDTH * AREA_HEIGHT must be a power of 2 i.e. valid values are 1, 2, 4, 8, 16, 32 etc.
//
// The number of areas must be <= 255, therefore:
//	 ( ((ceilf(PIXELS_WIDTH / VIDEO_SCALING) / AREA_WIDTH) * 2 + 
//	   ((ceilf(PIXELS_HEIGHT / VIDEO_SCALING) / AREA_WIDTH) * 2 ) must be less than 255
#define AREA_WIDTH 1	// >=1 and integer:  Typically 1 or 2 (if you have fewer LEDs per strip)
#define AREA_DEPTH 8	// >=1 and integer:  Start at 8, and reduce after you've tuned CELLGRID_BOUNDS

// Defining the letter box ratio avoids having to change the CELLGRID_BOUNDS and LEDS_BOUNDS
// for different Letterbox formats at the same resolution.
// To use this, define CELLGRID_BOUNDS / LEDS_BOUNDS for the base resolution defined in PIXELS_WIDTH/HEIGHT,
// and then generate configs with a different LETTERBOX_RATIO for the letterboxes required
// Note that the base letterbox ratio is calculated from PIXELS_WIDTH/HEIGHT, so if that ratio is 1.77,
// and LETTERBOX_RATIO is 1.77, then there is no change made to the bounds of the screen
// Letterbox ratio must be > 0.0
#define LETTERBOX_RATIO 1.77	// 16:9
//#define LETTERBOX_RATIO 2.40	// Modern anamorphic (2-4-0)
//#define LETTERBOX_RATIO 1.33	// 4:3

// If the span of leds exceed the displayed picture area, there will be leds that should be dark,
// but because they are not are causing leds to not line up with the picture.
// Force the leds to be ignored by adjusting the bounds of the LED causing outermost leds to be ignored 
#define LEDS_BOUNDS_START_X_OFFSET 	0	// Adjustment to the first led we want to use, must be >=0, typically <=2 and integer
#define LEDS_BOUNDS_END_X_OFFSET	0	// Adjustment to the last led we want to use, must be <= 0, typically >=-2 and integer
#define LEDS_BOUNDS_START_Y_OFFSET 	0	// Adjustment to the first led we want to use, must be >=0, typically <=2 and integer
#define LEDS_BOUNDS_END_Y_OFFSET	0	// Adjustment to the last led we want to use, must be <=0, typically <=-2 and integer

// The color value for the output table for leds in use
#define COLOR_ACTIVE 0

// The color value for the output table for leds that are disabled
// Set this color in the color_N.conf to black (0's for everything)
#define COLOR_DISABLED 1

// The gamma value for the output table
#define GAMMA 1




// DO NOT CHANGE BELOW HERE
#define VIDEO_SCALING 32	// Incoming video is scaled down by this amount in X/Y by the FPGA.  I.e. 1920x1080 / 32 = 60x33
				// Scaling is independent of resolution, so 640x480 is 20x15

#define AREA_CONF		"area.conf"
#define OUTPUT_CONF_PART1	"output_"
#define OUTPUT_CONF_PART2	".conf"

#define LEDS_WIDTH  ((LEDS_X) + (LEDS_BOUNDS_END_X_OFFSET) - (LEDS_BOUNDS_START_X_OFFSET))
#define LEDS_HEIGHT ((LEDS_Y) + (LEDS_BOUNDS_END_Y_OFFSET) - (LEDS_BOUNDS_START_Y_OFFSET))

#define LETTERBOX_FUDGE_FACTOR (0.01)

#define SCREEN_ASPECT_RATIO ((float)(PIXELS_WIDTH) / (float)(PIXELS_HEIGHT))



// Returns true if v is integer
// otherwise false

int isInteger(float v)
{
	if (((float)((int)v)) == v )	return 1;
	else				return 0;
}



// Verifies the settings are valid
// Returns true if okay, otherwise false

int verifySettings(void)
{
	if ( OUTPUT_NUM < 0 || OUTPUT_NUM > 7 || ( ! isInteger(OUTPUT_NUM) ) )	{fprintf(stderr, "Error: OUTPUT_NUM should be 0..7 and integer\n");return 0;}
	if ( PIXELS_WIDTH < 1 || (! isInteger(PIXELS_WIDTH) ) )			{fprintf(stderr, "Error: PIXELS_WIDTH should be >=1 and integer\n");return 0;}
	if ( PIXELS_HEIGHT < 1 || (! isInteger(PIXELS_HEIGHT) ) )		{fprintf(stderr, "Error: PIXELS_HEIGHT should be >=1 and integer\n");return 0;}
	if ( LEDS_X < 1 || (! isInteger(LEDS_X) ) )				{fprintf(stderr, "Error: LEDS_X should be >=1 and integer\n");return 0;}
	if ( LEDS_Y < 1 || (! isInteger(LEDS_Y) ) )				{fprintf(stderr, "Error: LEDS_Y should be >=1 and integer\n");return 0;}

	if (( LEDS_X * 2 + LEDS_Y * 2 ) > 512)
		{fprintf(stderr, "Error: Total number of LEDs is greater than 512 and will exceed 1 output, this utility is not for you!\n");return 0;}

	if ( CELLGRID_BOUNDS_START_X_OFFSET < 0 || (! isInteger(CELLGRID_BOUNDS_START_X_OFFSET) ) )
										{fprintf(stderr, "Error: CELLGRID_BOUNDS_START_X_OFFSET should be >=0 and integer\n");return 0;}
	if ( ! isInteger(CELLGRID_BOUNDS_END_X_OFFSET) )			{fprintf(stderr, "Error: CELLGRID_BOUNDS_END_X_OFFSET should be integer\n");return 0;}
	if ( CELLGRID_BOUNDS_START_Y_OFFSET < 0 || (! isInteger(CELLGRID_BOUNDS_START_Y_OFFSET) ) )
										{fprintf(stderr, "Error: CELLGRID_BOUNDS_START_Y_OFFSET should be >=0 and integer\n");return 0;}
	if ( ! isInteger(CELLGRID_BOUNDS_END_Y_OFFSET) )			{fprintf(stderr, "Error: CELLGRID_BOUNDS_END_Y_OFFSET should be integer\n");return 0;}
	if ( AREA_WIDTH < 1 || (! isInteger(AREA_WIDTH) ) )			{fprintf(stderr, "Error: AREA_WIDTH should be >=1 and integer\n");return 0;}
	if ( AREA_DEPTH < 1 || (! isInteger(AREA_DEPTH) ) )			{fprintf(stderr, "Error: AREA_DEPTH should be >=1 and integer\n");return 0;}
	
	// Test for a power of 2 by shifting to the right
	int size = AREA_WIDTH * AREA_DEPTH;
	while ( size > 0 )
	{
		// Tes for more than one bit set
		if ( size > 1 && (size & 1))	break;
		size >>= 1;	// Shift right
	}

	// If size is not zero, then we broke out of the while above due to more than one bit being set
	// If size is 0, then we only had one bit set (i.e. a power of 2)
	if ( size )	{fprintf(stderr, "Error: AREA_WIDTH * AREA_DEPTH should be a power of 2\n");return 0;}

	if  ( ((ceilf((float)PIXELS_WIDTH  / (float)VIDEO_SCALING) / (float)AREA_WIDTH) * 2.0 +
	      ((ceilf((float)PIXELS_HEIGHT / (float)VIDEO_SCALING) / (float)AREA_WIDTH) * 2.0) ) > 255.0 )
			{fprintf(stderr, "Error: 255 Areas exceeded, increase AREA_WIDTH by 1\n");return 0;}

	if ( LEDS_BOUNDS_START_X_OFFSET < 0 || ( ! isInteger(LEDS_BOUNDS_START_X_OFFSET) ) )
		{fprintf(stderr, "Error: LEDS_BOUNDS_START_X_OFFSET should be >=0 and integer\n");return 0;}
	if ( LEDS_BOUNDS_START_Y_OFFSET < 0 || ( ! isInteger(LEDS_BOUNDS_START_Y_OFFSET) ) )
		{fprintf(stderr, "Error: LEDS_BOUNDS_START_Y_OFFSET should be >=0 and integer\n");return 0;}
	if ( LEDS_BOUNDS_END_X_OFFSET > 0 || ( ! isInteger(LEDS_BOUNDS_END_X_OFFSET) ) )
		{fprintf(stderr, "Error: LEDS_BOUNDS_END_X_OFFSET should be <=0 and integer\n");return 0;}
	if ( LEDS_BOUNDS_END_Y_OFFSET > 0 || ( ! isInteger(LEDS_BOUNDS_END_Y_OFFSET) ) )
		{fprintf(stderr, "Error: LEDS_BOUNDS_END_Y_OFFSET should be <=0 and integer\n");return 0;}

	if ( LETTERBOX_RATIO <= 0.0 )
		{fprintf(stderr, "Error: LETTER_BOX_RATIO should be >0.0\n");return 0;}
	
	return 1;
}



void areaConfHeader(FILE *fp)
{
	fprintf(fp, "# xmin  xmax  ymin  ymax  divshift area_number\n");
}



FILE *areaConfCreate(void)
{
	FILE *fp, *fopen();

	if (( fp = fopen(AREA_CONF, "w")) == NULL )
		perror(AREA_CONF);

	return fp;
}



void outputConfHeader(FILE *fp)
{
	fprintf(fp, "# index    area    colour    gamma    enable\n");
}



FILE *outputConfCreate(void)
{
	char filename[20];
	FILE *fp, *fopen();

	sprintf(filename, "%s%d%s", OUTPUT_CONF_PART1, OUTPUT_NUM, OUTPUT_CONF_PART2);
	if (( fp = fopen(filename, "w")) == NULL )
		perror(filename);

	return fp;
}



int areaConfGenerate(FILE *fp, int *areasX, int *areasY, float letterBoxXPercent, float letterBoxYPercent)
{
	int i, divshift = 0;

	*areasX = *areasY = 0;

	// Figure out divshift, which is a power of 2, we do this by shifting until areaArea is 0
	int areaArea = AREA_WIDTH * AREA_DEPTH;

	while ( ( areaArea >>= 1 ) )
		divshift ++;
	
	printf("divshift calculated: %d\n", divshift);

	// Calculate the min and max cell values
	int cellMaxX = (int)ceilf((float)PIXELS_WIDTH  / (float)VIDEO_SCALING);
	int cellMaxY = (int)ceilf((float)PIXELS_HEIGHT / (float)VIDEO_SCALING);
	int cellMinX = 0;
	int cellMinY = 0;

	// Adjust the min/max cell values by the bounds offset
	cellMinX += CELLGRID_BOUNDS_START_X_OFFSET;
	cellMaxX += CELLGRID_BOUNDS_END_X_OFFSET;
	cellMinY += CELLGRID_BOUNDS_START_Y_OFFSET;
	cellMaxY += CELLGRID_BOUNDS_END_Y_OFFSET;

	// Figure out the letterbox adjustment
	int letterBoxXAdjust, letterBoxYAdjust;

	if ( letterBoxXPercent == 1.0 )
		letterBoxXAdjust = 0;
	else	letterBoxXAdjust = (int)((1.0 - letterBoxXPercent) * (float)((cellMaxX - cellMinX) + 1) * 0.5);

	if ( letterBoxYPercent == 1.0 )
		letterBoxYAdjust = 0;
	else	letterBoxYAdjust = (int)((1.0 - letterBoxYPercent) * (float)((cellMaxY - cellMinY) + 1) * 0.5);


	int countAreas = 0;

	// Top row running left to right
	fprintf(fp, "# Top Row running left to right\n");
	areaConfHeader(fp);
	for ( i = cellMinX; i <= cellMaxX; i += AREA_WIDTH )
		{ fprintf(fp, "  %-5d %-5d %-5d %-5d %-8d # %d\n", i, (i + AREA_WIDTH) - 1, letterBoxYAdjust + cellMinY, letterBoxYAdjust + (cellMinY + AREA_DEPTH) - 1, divshift, countAreas++); (*areasX) ++; }
	
	// Right column running top to bottom
	fprintf(fp, "# Right Column running top to bottom\n");
	areaConfHeader(fp);
	for ( i = cellMinY; i <= cellMaxY; i += AREA_WIDTH )
		{ fprintf(fp, "  %-5d %-5d %-5d %-5d %-8d # %d\n", -letterBoxXAdjust + (cellMaxX - AREA_DEPTH) + 1, -letterBoxXAdjust + cellMaxX, i, (i + AREA_WIDTH) - 1, divshift, countAreas++); (*areasY) ++; }

	// Bottom row running left to right
	fprintf(fp, "# Bottom Row running left to right\n");
	areaConfHeader(fp);
	for ( i = cellMinX; i <= cellMaxX; i += AREA_WIDTH )
		{ fprintf(fp, "  %-5d %-5d %-5d %-5d %-8d # %d\n", i, (i + AREA_WIDTH) - 1, -letterBoxYAdjust + (cellMaxY - AREA_DEPTH) + 1, -letterBoxYAdjust + cellMaxY, divshift, countAreas++); }

	// Left column running top to bottom
	fprintf(fp, "# Left Column running top to bottom\n");
	areaConfHeader(fp);
	for ( i = cellMinY; i <= cellMaxY; i += AREA_WIDTH )
		{ fprintf(fp, "  %-5d %-5d %-5d %-5d %-8d # %d\n", letterBoxXAdjust + cellMinX, letterBoxXAdjust + (cellMinX + AREA_DEPTH ) - 1, i, (i + AREA_WIDTH) - 1, divshift, countAreas++); }

	printf("Number of areas: %d XAreas: %d YAreas: %d\n", countAreas, *areasX, *areasY);

	return countAreas;
}



int getAreaForLedX(int ind, int areasX)
{
	return (int)(((float)ind / (float)LEDS_WIDTH) * (float)areasX);
}



int getAreaForLedY(int ind, int areasY)
{
	return (int)(((float)ind / (float)LEDS_HEIGHT) * (float)areasY);
}



int dumpDisabledLed(FILE *fp, int count, int ledCount)
{
	int i;

	for ( i = 0; i < count; i ++, ledCount ++ )
		fprintf(fp, "%7d %7d %9d %8d %9d\n", ledCount, 0, COLOR_DISABLED, GAMMA, 1);

	return ledCount++;
}



int dumpActiveLed(FILE *fp, int from, int to, int ledCount, int baseArea, int x, int areas)
{
	int i;

	if 	( to > from )
	{
		for ( i = from; i < to; i ++, ledCount ++ )
			fprintf(fp, "%7d %7d %9d %8d %9d\n", ledCount, baseArea + ((x) ? getAreaForLedX(i, areas) : getAreaForLedY(i, areas)), COLOR_ACTIVE, GAMMA, 1);
	}
	else if ( to < from )
	{
		for ( i = from - 1; i >= to; i --, ledCount ++ )
			fprintf(fp, "%7d %7d %9d %8d %9d\n", ledCount, baseArea + ((x) ? getAreaForLedX(i, areas) : getAreaForLedY(i, areas)), COLOR_ACTIVE, GAMMA, 1);
	}


	return ledCount;
}



int aspectRatioMatch(float aspectRatio1, float aspectRatio2)
{
	if ( fabsf(aspectRatio2 - aspectRatio1) <= LETTERBOX_FUDGE_FACTOR ) return 1;
	return 0;
}



// Figure out the percentage (0-1) we need to adjust X or Y for letter boxing

void calculateLetterBoxAdjustment(float *letterBoxXPercent, float *letterBoxYPercent)
{
	if ( aspectRatioMatch( SCREEN_ASPECT_RATIO, LETTERBOX_RATIO ) )
	{
		*letterBoxXPercent = *letterBoxYPercent = 1.0;
	}
	else if ( (LETTERBOX_RATIO) > SCREEN_ASPECT_RATIO )
	{
		*letterBoxXPercent = 1.0;
		*letterBoxYPercent = SCREEN_ASPECT_RATIO / (LETTERBOX_RATIO); 
	}
	else if ( (LETTERBOX_RATIO) < SCREEN_ASPECT_RATIO )
	{
		*letterBoxXPercent = (LETTERBOX_RATIO) / SCREEN_ASPECT_RATIO; 
		*letterBoxYPercent = 1.0;
	}	
}



void outputConfGenerate(FILE *fp, int areasX, int areasY)
{
	int i, ledCount = 0, baseArea = 0;

	// Top Row running left to right
	fprintf(fp, "# Top Row running left to right\n");
	outputConfHeader(fp);
	ledCount = dumpDisabledLed(fp, LEDS_BOUNDS_START_X_OFFSET, ledCount);
	ledCount = dumpActiveLed(fp, 0, LEDS_WIDTH, ledCount, baseArea, 1, areasX);
	ledCount = dumpDisabledLed(fp, -LEDS_BOUNDS_END_X_OFFSET, ledCount);

	// Right Column running top to bottom
	fprintf(fp, "# Right Column running top to bottom\n");
	outputConfHeader(fp);
	baseArea += areasX;
	ledCount = dumpDisabledLed(fp, LEDS_BOUNDS_START_Y_OFFSET, ledCount);
	ledCount = dumpActiveLed(fp, 0, LEDS_HEIGHT, ledCount, baseArea, 0, areasY);
	ledCount = dumpDisabledLed(fp, -LEDS_BOUNDS_END_Y_OFFSET, ledCount);

	// Bottom Row running right to left
	fprintf(fp, "# Bottom Row running right to left\n");
	outputConfHeader(fp);
	baseArea += areasY;
	ledCount = dumpDisabledLed(fp, -LEDS_BOUNDS_END_X_OFFSET, ledCount);
	ledCount = dumpActiveLed(fp, LEDS_WIDTH, 0, ledCount, baseArea, 1, areasX);
	ledCount = dumpDisabledLed(fp, LEDS_BOUNDS_START_X_OFFSET, ledCount);

	// Left Column running bottom to top
	fprintf(fp, "# Left Column running bottom to top\n");
	outputConfHeader(fp);
	baseArea += areasX;
	ledCount = dumpDisabledLed(fp, -LEDS_BOUNDS_END_Y_OFFSET, ledCount);
	ledCount = dumpActiveLed(fp, LEDS_HEIGHT, 0, ledCount, baseArea, 0, areasY);
	ledCount = dumpDisabledLed(fp, LEDS_BOUNDS_START_Y_OFFSET, ledCount);

	printf("%d leds written to output, filled to 512\n", ledCount);

	// Disable the remainder of the leds in the channel
	fprintf(fp, "# Remaining LEDs are disabled\n");
	outputConfHeader(fp);
	ledCount = dumpDisabledLed(fp, 512-ledCount, ledCount);
}



int main(void)
{
	int areasX, areasY;
	FILE *areaConfFp, *outputConfFp;
	float letterBoxYPercent, letterBoxXPercent;

	if ( ! verifySettings() )	return 1;

	// Open the files and create the headers
	if (( areaConfFp   = areaConfCreate()   ) == NULL )	return 2;
	if (( outputConfFp = outputConfCreate() ) == NULL )	return 3;

	// Calculate the adjustment for letter boxing
	calculateLetterBoxAdjustment(&letterBoxXPercent, &letterBoxYPercent);

	// Generate area file contents
	areaConfGenerate(areaConfFp, &areasX, &areasY, letterBoxXPercent, letterBoxYPercent);

	// Generate output file contents
	outputConfGenerate(outputConfFp, areasX, areasY);

	// Close the files
	fclose(outputConfFp);
	fclose(areaConfFp);

	return 0;
}

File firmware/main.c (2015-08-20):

/*

   Copyright (C) 2013 Stephen Robinson
  
   This file is part of HDMI-Light
  
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
*/

#include <inttypes.h>
#include <avr/io.h>
#include <avr/pgmspace.h>
#include <avr/interrupt.h>
#include <string.h>
#include <stdio.h>
#include "ambilight.h"
#include "serial.h"
#include "i2c.h"


// If this line is commented out, the ADV7611 will not be started
// at power on and HDMI handshaking will not occur, in which case "R"
// needs to be run from the serial console to start the ADV7611
#define AUTO_INITIALIZATION

// Uncomment to enable power on/off via physical switch.
// Requires a pull-up resistor and switch to be added.
//#define ENABLE_POWER_SWITCH

#define BELL    '\a'


uint8_t silent = 0;
volatile uint8_t g_formatChanged = 0;
volatile uint8_t g_cecMessage[16];
volatile uint8_t g_cecMessageLength;


ISR(_VECTOR(1))
{
	g_formatChanged = 1;
	INT_CLEAR = 1;
}

ISR(_VECTOR(2))
{
	uint8_t cecRxIntState = i2cRead(0x98, 0x93);

	// if this is a CEC RX message 0 ready interupt
	if(cecRxIntState & 8)
	{
		int i;

		// copy the received message
		g_cecMessageLength = i2cRead(0x80, 0x25);
		if(g_cecMessageLength > sizeof(g_cecMessage))
			g_cecMessageLength = sizeof(g_cecMessage);
		for(i = 0; i < g_cecMessageLength; ++i)
			g_cecMessage[i] = i2cRead(0x80, 0x15 + i);

		// clear the message buffer ready for a new message
		i2cWrite(0x80, 0x2C, 0x02);

		// clear the interrupt
		i2cWrite(0x98, 0x94, 0x08);
	}
}

void idle()
{
#ifdef ENABLE_POWER_SWITCH
	static uint8_t debounceValue = 0;
	static uint8_t debounceTicks = 0;
#endif // ENABLE_POWER_SWITCH

	if(g_formatChanged)
	{
		changeFormat();
		g_formatChanged = 0;
	}

	if(g_cecMessageLength != 0)
	{
		cli();
		processCecMessage();
		g_cecMessageLength = 0;
		sei();
	}

#ifdef ENABLE_POWER_SWITCH
	if((PIND & (1 << GPIO_POWER_PIN)) == debounceValue)
	{
		if(debounceTicks == DEBOUNCE_TICK_COUNT)
		{
			if(debounceValue)
				powerOn();
			else
				powerOff();
			++debounceTicks;
		}
		else if(debounceTicks < DEBOUNCE_TICK_COUNT)
			++debounceTicks;
	}
	else
	{
		debounceValue = PIND & (1 << GPIO_POWER_PIN);
		debounceTicks = 0;
	}
#endif // ENABLE_POWER_SWITCH
}

// Print a section of the ring buffer to stdout, wrapping around when passing the end.
// Also replacing NULLs with spaces as old commands have had spaces replaced with NULLs
// when they were being split into args
void ringBufPrint(char* buf, uint8_t pos, int len)
{
	while(len--)
	{
		if(buf[pos] == '\0')
			fputc(' ', stdout);
		else
			fputc(buf[pos], stdout);
		++pos;
	}
}

void ringBufCopy(char* buf, uint8_t dst, uint8_t src, int len)
{
	while(len--)
		buf[dst++] = buf[src++];
}

void ringBufCopyReverse(char* buf, uint8_t dst, uint8_t src, int len)
{
	dst += len;
	src += len;
	while(len--)
		buf[--dst] = buf[--src];
}

char readcmd(char** argv, char maxargs)
{
	static char cmdbuf[256] = {0, 0};
	static unsigned char current = 0;

	unsigned char history = 0;
	unsigned char pos = current + 1;
	unsigned char end = current + 1;
	unsigned char arg;


	while(1)
	{
		int c = serial_getchar();
		if(c == -1)
		{
			idle();
			continue;
		}

		switch(c)
		{
			case 0x1B:
				while((c = serial_getchar()) == -1)
					;
				if(c == '[')
				{
					while((c = serial_getchar()) == -1)
						;
					switch(c)
					{
						case 'A': goto UP;
						case 'B': goto DOWN;
						case 'C': goto RIGHT;
						case 'D': goto LEFT;
					}
				}
				break;
			LEFT:
			case 0x02: // left
				if(pos - 1 != current)
				{
					--pos;
					printf_P(PSTR("\x1B[D")); // move left
				}
				else
					serial_putchar(BELL);
				break;
			case 0x08: // backspace
			case 0x7f:
				if(pos > 0)
				{
					// move partial line left in buffer to fill hole
					ringBufCopy(cmdbuf, pos - 1, pos, end - pos);
					--pos; --end;

					// move cursor left one place and print the partial line
					printf_P(PSTR("\x1B[D"));
					ringBufPrint(cmdbuf, pos, end - pos);

					// move the cursor left, back to the edit position
					printf_P(PSTR(" \x1B[%dD"), end - pos + 1);
				}
				else
					serial_putchar(BELL);
				break;
			RIGHT:
			case 0x06: // right
				if(pos + 1 != end)
				{
					++pos;
					printf_P(PSTR("\x1B[C")); // move right
				}
				else
					serial_putchar(BELL);
				break;
			case '\n':
			case '\r':
				goto DONE;
			UP:
			case 0x10:
				if(1)
				{
					unsigned char p = current;
					unsigned char len = 0;
					unsigned char i;

					for(i = 0; i < history + 1; ++i)
					{
						len = cmdbuf[p];
						if(len == 0)
							break;
						p -= len;
					}
					if(i == history + 1)
					{
						++history;

						// lines in the history are NULL terminated, remove the termination
						--len;

						// copy the old line into the current position in the buffer
						ringBufCopy(cmdbuf, current + 1, p + 1, len - 1);
						cmdbuf[current + len] = '\0';

						// move the cursor to the beginning of the line and print the copied line
						printf_P(PSTR(" \x1B[%dD"), pos - current);
						ringBufPrint(cmdbuf, current + 1, len - 1);

						// if the copied line is shorter then overwrite any extra characters with spaces
						if(end - (current + len) > 0)
						{
							for(i = 0; i < end - (current + len); ++i)
								serial_putchar(' ');
							printf_P(PSTR("\x1B[%dD"), end - (current + len));
						}
						end = current + len;
						pos = end;
					}
					else
						serial_putchar(BELL);
				}
				break;
			DOWN:
			case 0x0E:
				if(history > 1)
				{
					unsigned char p = current;
					unsigned char len;
					unsigned char i;

					--history;
					for(i = 0; i < history; ++i)
					{
						len = cmdbuf[p];
						if(len == 0)
							break;
						p -= len;
					}

					// the lines in the history are NULL terminated, remove the termination
					--len;

					// copy the old line to the current position in the buffer
					ringBufCopy(cmdbuf, current + 1, p + 1, len - 1);
					cmdbuf[current + len] = '\0';

					// move the cursor to the beginning of the line and print the copied line
					printf_P(PSTR(" \x1B[%dD"), pos - current);
					ringBufPrint(cmdbuf, current + 1, len - 1);

					// if the copied line is shorter then overwrite the extra characters with spaces
					if(end - (current + len) > 0)
					{
						for(i = 0; i < end - (current + len); ++i)
							serial_putchar(' ');
						printf_P(PSTR("\x1B[%dD"), end - (current + len));
					}
					end = current + len;
					pos = end;
				}
				else if(history == 1)
				{
				}
				else
					serial_putchar(BELL);
				break;
			default:
				if(end + 1 != current)
				{
					// copy any characters after the current edit point to the right to make room
					ringBufCopyReverse(cmdbuf, pos + 1, pos, end - pos);

					// add the new character
					cmdbuf[pos] = c;

					// print the buffer from the current edit point to the end
					ringBufPrint(cmdbuf, pos, end - pos + 1);

					// move the cursor back to the edit point
					printf_P(PSTR(" \x1B[%dD"), end - pos + 1);
					++pos;
					++end;

				}
				else
					serial_putchar(BELL);
				break;
		}
	}
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

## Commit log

2013-11-26 Initial import
    [hdmilight.brd, hdmilight.sch]
2013-12-02 changed firmware to automatically apply configuration at powerup
2013-12-02 Added PNG of HDMI board schematic
2014-08-30 Fixed firmware build errors with avr-gcc 4.8
    [main.c]
2014-10-18 Added support for delaying output by up to 8 frames. Currently untested and missing configuration interface
2014-10-19 Reworked configuration interface to allow for multiple config rams and registers
    [main.c]
2014-10-26 Added per output colour transformation, per output gamma correction, output mapping table for each output to select area/colour-coefficients/gamma-table for up to 512 LEDs per output (4096 total LEDs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
    [main.c]
2014-11-02 fixed result retreival debug interface
    [main.c]
2014-11-02 updated firmware to fix setting of colour coefficients
    [main.c]
2014-11-08 fixed I2C firmware Get/Set commands to allow access to all devices not just the mapper
    [cmd_i2c.c]
2014-11-08 moved EDID from the main ADV7611 I2C config table to its own file for easier maintenance, also updated EDID content to declare 1920x1080 as native resolution
2014-11-09 added clock enable to AVR CPU to allow it to be stopped during DMA transfers
2014-11-14 fixed value of HDMI pull up resistors on receiver board
    [hdmilight.brd, hdmilight.sch]
2014-11-14 added ODDR2 to forward clock to SPI clock pin so the clock doesn't need to leave the clock nets and enter the main fabric
2014-11-23 fixed halting CPU during DMA transfers
2014-11-23 fixed config address generation, added third set of config files for 1.33:1
    [main.c]
2014-11-24 general firmware cleanup: config commands renamed to reset, light commands renamed to areas, better help text, area config table removed, old printf files removed
    [cmd_i2c.c]
2014-12-03 fixed skipping of disabled LEDs when distributing results to outputs
2014-12-21 added missing capacitor values to schematic
    [hdmilight.brd, hdmilight.sch]
2014-12-21 removed power jack from HDMI receiver board
    [hdmilight.brd, hdmilight.sch]
2014-12-22 receiver board: replaced TXB0108 level shifter with a 74HCT541
    [hdmilight.brd, hdmilight.sch]
2014-12-22 receiver board: changed value of IP4776CZ38 ESD protection IC to TPD12S520
    [hdmilight.brd, hdmilight.sch]
2014-12-23 receiver board: merged changes from Jet:
    * added "power" and "hotplug" LED labels
    * added LED polarity symbols
    * moved C7/C8 labels off of vias
    * moved vias from under SCL and RST labels
    * moved vias from under R13/14/15 labels
    * added + symbols on polarised caps C7-14
    * added R16: 10K between VCC_3V3 and TPD12S520 LV_SUPPLY
    * increased drill size for ADV7611 ground pad from 12mil to 13mil
    * fixed schematic net labels
    also changed:
    * edited pin header package to remove the "1" and "16" labels
    * added channel number labels to output channel header
    * changed all text to same vector font
    * added OSHW logo
    [hdmilight.brd, hdmilight.sch]
2014-12-23 receiver board: added BOM created by Jet after the following minor changes:
    * removed C20
    * changed C35 from 0603 to 0402
    * removed power jack
    * changed 74HCT245 to 74HCT541
    * C1, C4, etc.: changed Farnell part number to a X7R part
2014-12-27 receiver board: fixed unrouted wire on C35 spotted by Jet
    [hdmilight.brd]
2014-12-27 receiver board: fixed wrong Mouser part number for 74HCT541, spotted by Jet
2014-12-31 receiver board: updated BOM: fixed total count for 0.1uF capacitors and removed non-existant R17, R19
2014-12-31 receiver board: BOM: added 2x4 stackable socket to pass through unused pins
2014-12-31 receiver board: added v1.1 gerbers
2015-01-31 Patch from Jet: Made PROGMEM variables const to fix compiling with newer versions of avr-gcc and re-enabled automatic initialisation
    [main.c]
2015-01-31 receiver board: removed untested warning from v1.1 gerbers zip file
2015-01-31 receiver board: removed untested warning from Eagle CAD board layout
    [hdmilight.brd]
2015-01-31 receiver board: renamed BOM to BOM-v1.1
2015-01-31 receiver board: added PNG of v1.1 schematic
2015-02-01 updated .ucf file for v1.1 receiver board
2015-02-04 updated .ucf file for output pin ordering on v1.1 receiver board
2015-02-06 Fixed Get I2C firmware command, it was always reading from device 0x98. Also added bit range option to command.
    [cmd_i2c.c, main.c]
2015-02-06 Fixed HDMI input colour space selection, was forced to RGB, now auto selecting based on HDMI Info Frames Issue discovered by Jet
2015-02-06 Updated GetFormat command to display current active resolution and aspect ratio in addition to the existing raw values from the format detector
2015-02-08 Format changed interrupt now stays raised until cleared via write to port, ADV7611 INT1 made available to firmware
2015-02-08 added i2cWrite() function to remove duplicated code
2015-02-08 Started support for control via CEC Remote Pass Through Currently supports: * turning on/off * global brightness/contrast/hue/saturation * loading one of first 8 configurations (and disabling auto sw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
    All key codes are currently hard-coded
    Currently needs to be manually enabled via RK console command
2015-02-14 fixed bugs in serial terminal command history when wrapping around the ring buffer
    [main.c]
2015-02-15 Fixed CPU resets and other random behaviour when an interrupt is received during a DMA transfer
    [main.c]
2015-04-08 Connected the four unused pins to lower 4 bits of PORTD in AVR, used first pin as power on/off signal.
2015-08-20 Disabled power switch by default as it requires extra hardware

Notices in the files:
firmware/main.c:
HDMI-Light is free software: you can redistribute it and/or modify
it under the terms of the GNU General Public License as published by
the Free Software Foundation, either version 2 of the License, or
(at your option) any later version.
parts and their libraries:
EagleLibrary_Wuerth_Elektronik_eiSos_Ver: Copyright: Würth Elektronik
